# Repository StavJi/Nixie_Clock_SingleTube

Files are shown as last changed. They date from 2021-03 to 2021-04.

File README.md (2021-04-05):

# Nixie Clock with Single Tube
Big thanks to <a href="https://www.daliborfarny.com/">Dalibor Farny</a> for sharing desing files for his <a href="https://www.daliborfarny.com/product/blub-clock/">Blub Clock</a> case.

Time can be set using my <a href="https://github.com/StavJi/Nixie_Clock_SW">app</a> or via AT command interface with following UART setting 115200 bps, 8 data bits, no parity and 1 stop bit. To list all possible commands use ```AT$HELP?``` and you will get:

```
1. $HELP:Available commands:
2. AT$HELP
3. AT$DAY - (starts Monday) 1 to 7
4. AT$DATE -  1 to 31
5. AT$MONTH -  1 to 12
6. AT$YEAR -  2000 to 2099
7. AT$SEC -  0 to 59
8. AT$MIN -  0 to 59
9. AT$HOUR -  0 to 23
10. AT$DATE_TIME
11. AT$NIGHT_MODE -  0 to 1
```
<p float="left">
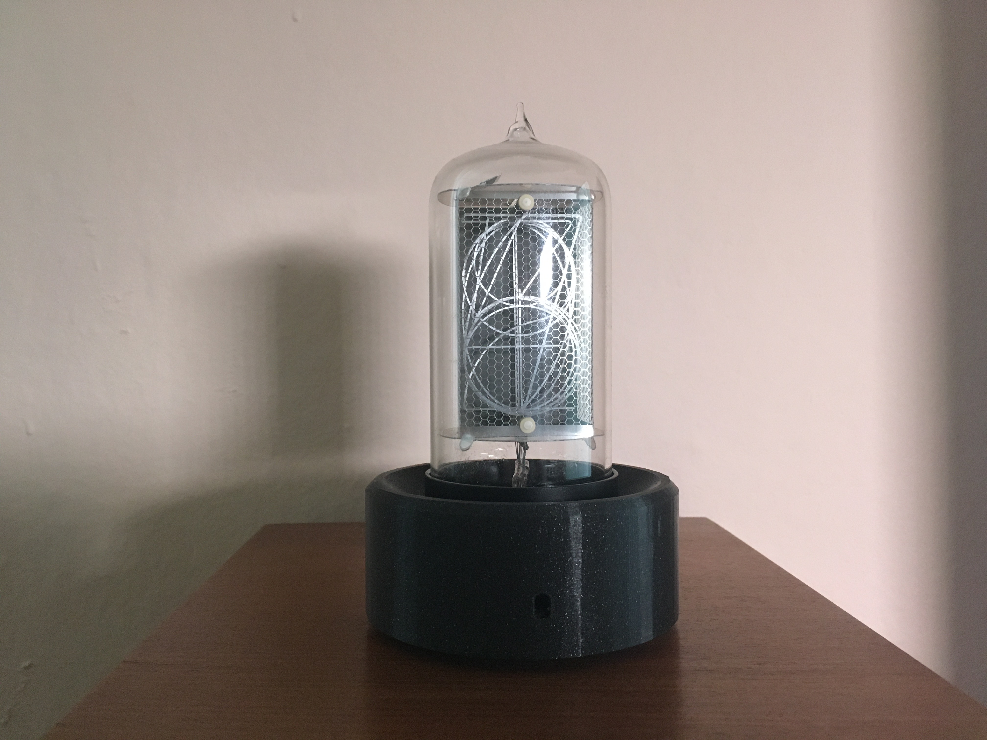
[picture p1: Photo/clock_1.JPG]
  
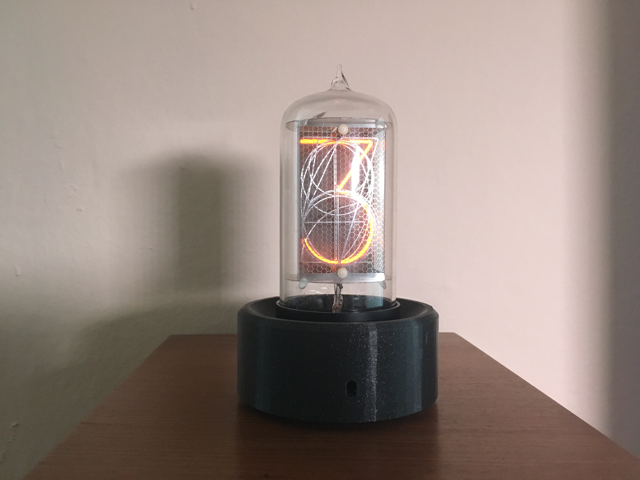
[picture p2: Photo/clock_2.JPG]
  
</p>

## TODO
- Add bluetooth driver
- Use Zephyr OS
- Create mobile APP

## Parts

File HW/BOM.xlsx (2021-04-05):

Part | Value | Qty | Package | Description
C1 | 1u | 1 | 805 | Capacitor
C2 | 100n | 1 | 805 | Capacitor
C3 | 10n | 1 | 603 | Capacitor
C4 | 100n | 1 | 805 | Capacitor
C5 | 10n | 1 | 603 | Capacitor
C6 | 100n | 1 | 805 | Capacitor
C7 | 10n | 1 | 603 | Capacitor
C8 | 100n | 1 | 805 | Capacitor
C9 | 1u | 1 | 805 | Capacitor
C10 | 100n | 1 | 805 | Capacitor
C11 | 100n | 1 | 805 | Capacitor
C12 | 100n | 1 | 805 | Capacitor
C13 | 100n | 1 | 805 | Capacitor
C14 | 100n | 1 | 805 | Capacitor
C15 | 1u | 1 | 805 | Capacitor
C16 | 100n | 1 | 805 | Capacitor
C17 | 100n | 1 | 1206 | Capacitor
C18 | 100n | 1 | 805 | Capacitor
C19 | 100n | 1 | 805 | Capacitor
C20 | 100n/250V | 1 | 2420 | Capacitor
C21 | 100n | 1 | 603 | Capacitor
C22 | 10u/16V | 1 | A | Capacitor
C23 | 100n | 1 | 805 | Capacitor
C24 | 100n/250V | 1 | 2420 | Capacitor
C25 | 10u/16V | 1 | A | Capacitor
C26 | 100n | 1 | 805 | Capacitor
C27 | 100n | 1 | 805 | Capacitor
C28 | 100u/16V | 1 | D | Capacitor
C29 | 100u/16V | 1 | D | Capacitor
C30 | 0,7p | 1 | 402 | Capacitor
C31 | 10u/16V | 1 | A | Capacitor
C32 | 4u7/250V | 1 | C_EL_3,5 | Capacitor
C59 | 0.22u/25V | 1 | 1206 | Capacitor
C63 | 100n | 1 | 1206 | Capacitor
C65 | 10u/16V | 1 | 1206 | Capacitor
C66 | 10u/16V | 1 | 1206 | Capacitor
C67 | 10u/16V | 1 | 1206 | Capacitor
D12 | US1G-E3/61T | 1 | DO-214AC | Diode
D19 | LL4148 | 1 | SOD-80 | Diode
FC1 | 47p | 1 | 805 | Feedthrough Capacitor
FC2 | 47p | 1 | 805 | Feedthrough Capacitor
FC3 | 47p | 1 | 805 | Feedthrough Capacitor
G3 | - | 1 | VL1220 | Battery
IC1 | MKW31Z512VHT4 | 1 | QFN48 | MCU
IC2 | OPT3001DNP | 1 | SON65P200X200X65-7N | Ambient Sensor
IC4 | MAX1771ESA | 1 | SO-8 | Step-Up DC-DC Controller
IC5 | TPS22810-Q1 | 1 | SOT23-6 | Load Switch 80mOhm with termal protection with sutdown Iq=0.5uA
IC6 | TPD2S017 | 1 | DBV | ESD Protection
IC7 | USBLC6-4SC6 | 1 | SOT-23-6L | Very low capacitance ESD protection 2 line
IC9 | MCP1700T-3302E | 1 | SOT89 | LDO Low Iq 200mA output
IC20 | FT232RL | 1 | SSOP28 | USB to UART convertor
IC3 | DS1339 | 1 | MSOP08 | RTC
IO2 | 4028 | 1 | SO16 | BCD to decimal DECODER
J1 | CX90M-16P | 1 | HRS_CX90M-16P | USB-C
JP2 | ANTCON | 1 | ANTCON | U.FL(m) Connector for DPS
L1 | 5,6nH | 1 | 402 | Inductor HF 5,6nH 300mA
L2 | 100nH | 1 | 1206 | Chip Inductors – 1206CS Series Low Inductance Coils
L3 | SRR4828A-121M | 1 | SRR4828A | Power Inductor
L5 | BLM21PG121SN1D | 1 | 805 | EMIFIL Chip Ferrite Bead for GHz Noise
LED1 | Green | 1 | 805 | LED
LED3 | Green | 1 | 805 | LED
Q1 | 32MHz | 1 | ECX1247B | Crystal
Q2 | CC5V-T1A 32.768KHz | 1 | 1206 | Crystal
R1 | 820R | 1 | 805 | Rezistor
R2 | 5k1 | 1 | 805 | Rezistor
R3 | 10k | 1 | 603 | Rezistor
R4 | 5k1 | 1 | 805 | Rezistor
R5 | 8k2 | 1 | 1206 | Rezistor
R6 | 4k7 | 1 | 805 | Rezistor
R7 | 100k | 1 | 1206 | Rezistor
R8 | 1M5 | 1 | 2512 | Rezistor
R9 | 4k7 | 1 | 805 | Rezistor
R10 | 0R | 1 | 603 | Rezistor
R11 | NC | 1 | 603 | Rezistor
R12 | 270k | 1 | 1206 | Rezistor
R27 | 13k | 1 | 805 | Rezistor
R29 | 470R | 1 | 805 | Rezistor
R32 | 4k7 | 1 | 805 | Rezistor
R33 | 4k7 | 1 | 805 | Rezistor
R34 | 4k7 | 1 | 805 | Rezistor
R35 | 4k7 | 1 | 805 | Rezistor
R36 | 4k7 | 1 | 805 | Rezistor
R37 | 4k7 | 1 | 805 | Rezistor
R38 | 4k7 | 1 | 805 | Rezistor
R39 | 4k7 | 1 | 805 | Rezistor
R40 | 4k7 | 1 | 805 | Rezistor
R41 | 4k7 | 1 | 805 | Rezistor
RSENSE | 0R050 | 1 | 2010 | Rezistor
T1 | BSC13DN30NSFDATMA1 | 1 | TRANS_BSC076N06NS3-G | Transistor: N-MOSFET
T2 | BCR108 | 1 | SOT-23 | NPN Transistror
T7 | MMBTA42 | 1 | SOT23-BEC | NPN Transistror
T8 | MMBTA42 | 1 | SOT23-BEC | NPN Transistror
T9 | MMBTA42 | 1 | SOT23-BEC | NPN Transistror
T10 | MMBTA42 | 1 | SOT23-BEC | NPN Transistror
T11 | MMBTA42 | 1 | SOT23-BEC | NPN Transistror
T12 | MMBTA42 | 1 | SOT23-BEC | NPN Transistror
T13 | MMBTA42 | 1 | SOT23-BEC | NPN Transistror
T14 | MMBTA42 | 1 | SOT23-BEC | NPN Transistror
T15 | MMBTA42 | 1 | SOT23-BEC | NPN Transistror
T16 | MMBTA42 | 1 | SOT23-BEC | NPN Transistror
V1 | RZ568M | 1 | - | Nixie Tube
- | H3161-01 | 11 | - | Nixie Tube Socket

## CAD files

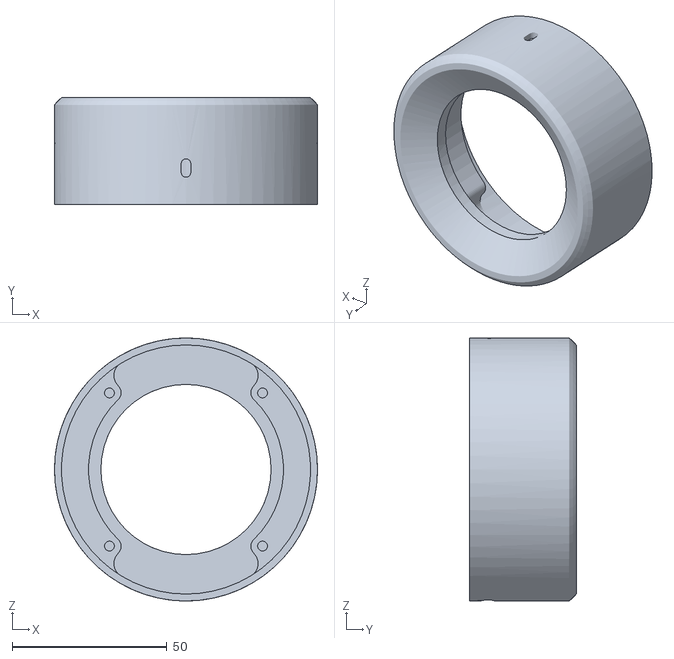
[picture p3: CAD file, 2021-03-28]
Case/Base.STL
85.0 x 34.7 x 85.0

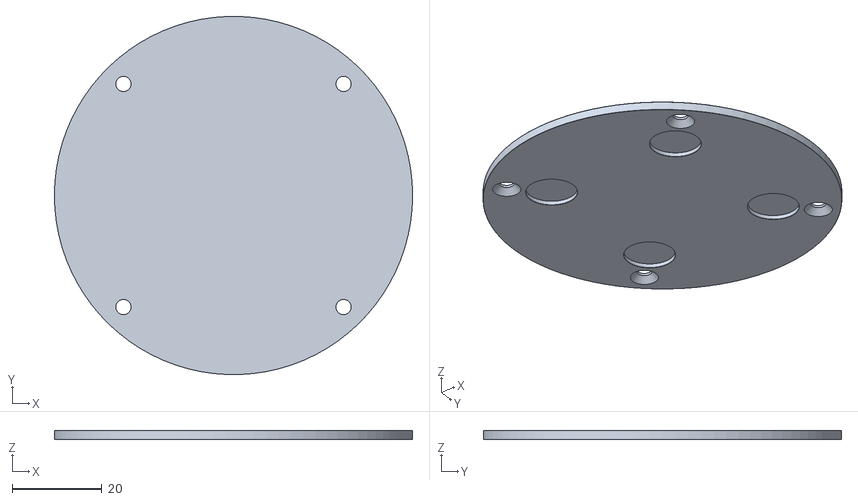
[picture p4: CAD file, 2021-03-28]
Case/Cover.STL
80.0 x 79.9 x 2.00

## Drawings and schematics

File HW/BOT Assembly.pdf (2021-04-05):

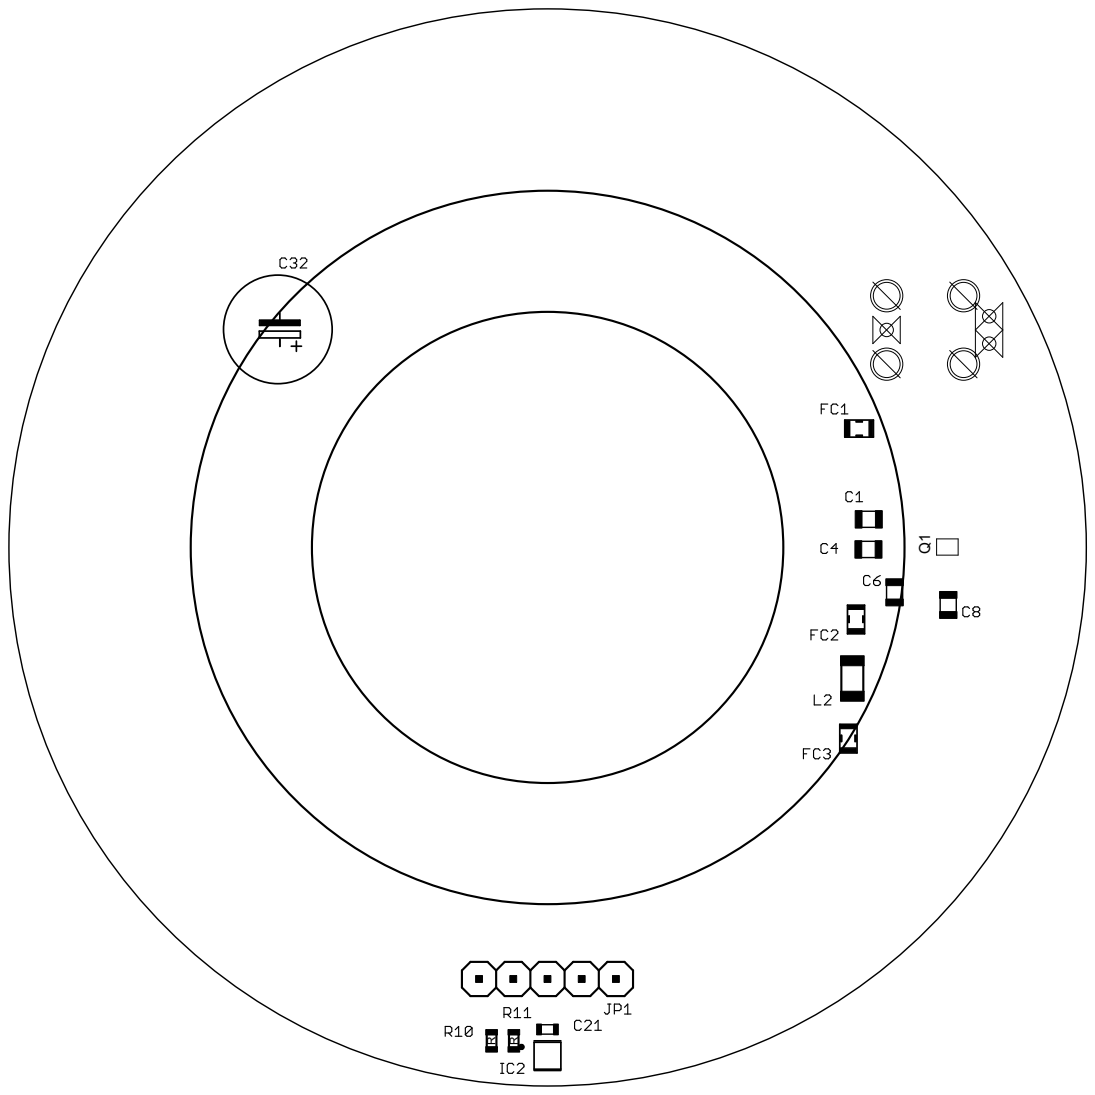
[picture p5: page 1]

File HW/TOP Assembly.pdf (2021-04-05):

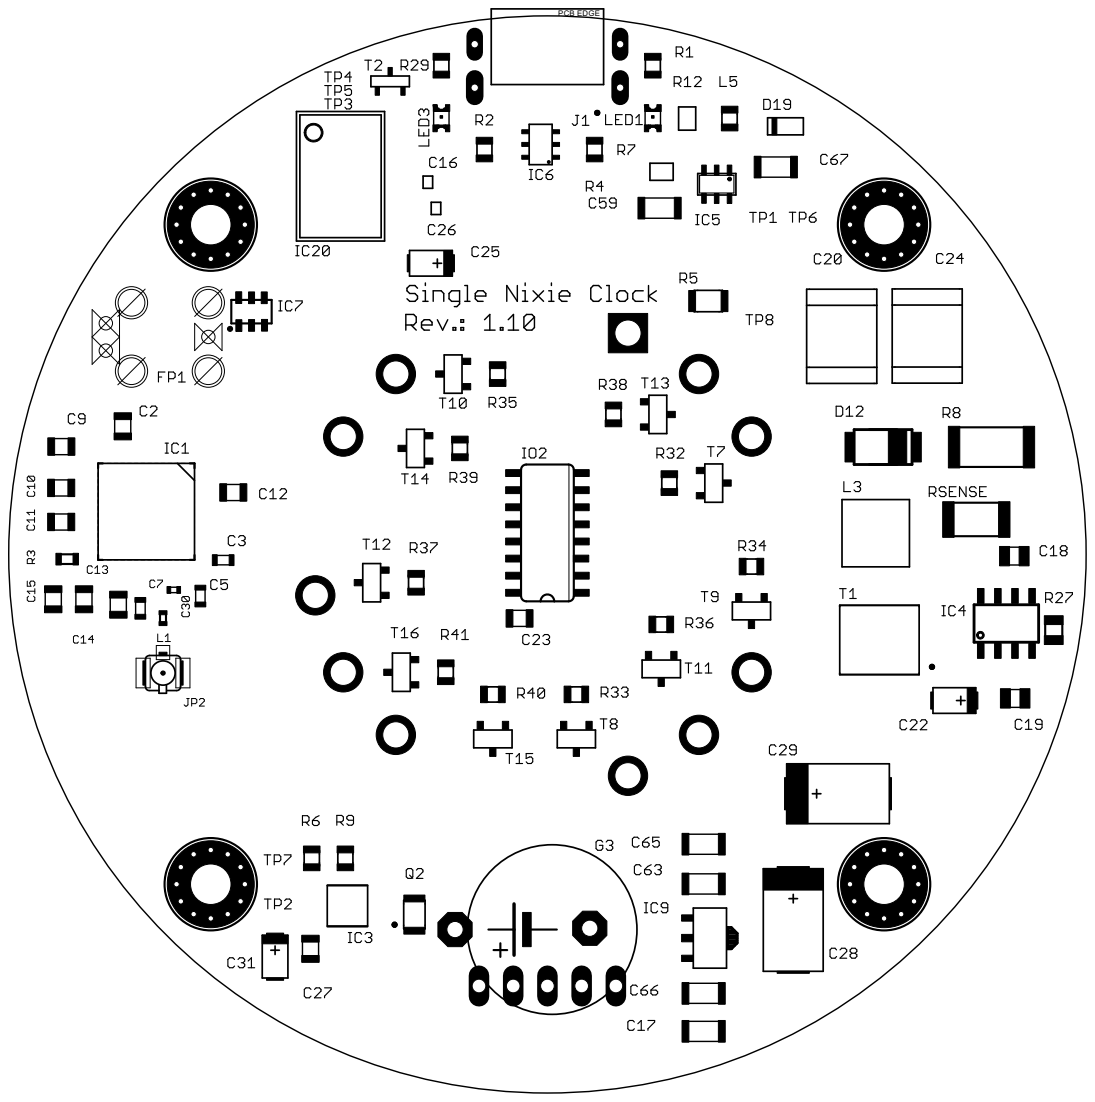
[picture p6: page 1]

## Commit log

2021-03-28 add files for 3D printer, photos of final clock, fw
    [Base.STL, Cover.STL]
2021-04-05 add BOM
    [BOM.xlsx]
2021-04-05 add gerber data, TOP and BOT assembly files
2021-04-05 fix: add 32KHz crystal to BOM and change RTC package
    [BOM.xlsx]
2021-04-05 fix: add el cap to HV output
    [BOM.xlsx]
2021-04-05 fix: remove old gerber files
